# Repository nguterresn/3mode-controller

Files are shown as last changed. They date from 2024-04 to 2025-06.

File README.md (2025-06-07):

## **Hardware Controller for Hobbyist Projects with ESPNow, nRF24, and Bluetooth**

This versatile hardware controller is designed to seamlessly integrate with a variety of wireless communication protocols, making it an ideal choice for hobbyist projects, DIY electronics, and prototyping. With support for **ESPNow**, **nRF24**, and **Bluetooth**, this controller offers unparalleled flexibility for creating custom communication setups across different platforms.

IMG_9709 – grande

### **Key Features:**

- **ESPNow**: Leverage ESP32's ESPNow protocol for fast, low-power, peer-to-peer communication between ESP32 devices. Perfect for IoT projects where devices need to communicate without relying on Wi-Fi or internet connections.
  
- **nRF24**: Incorporates the nRF24 wireless transceiver, enabling reliable and efficient communication for projects using the popular nRF24L01 radio module. Ideal for low-power, long-range wireless setups.

- **Bluetooth**: Equipped with Bluetooth support, allowing wireless connectivity with smartphones, tablets, and other Bluetooth-enabled devices. This makes it perfect for projects that require mobile app interaction or Bluetooth-based control.

- **Versatile Connectivity**: Easily switch between the three wireless protocols based on the requirements of your project, enabling communication over short or long distances, with low or high power consumption.

- **Easy-to-Use Interface**: Simple to interface with microcontrollers like ESP32 or Arduino, with available libraries and example code to get you started quickly.

- **Low Power Consumption**: Designed with power efficiency in mind, making it suitable for battery-powered projects, especially when using ESPNow or nRF24 protocols.

With its easy integration, low power consumption, and flexible wireless communication options, this hardware controller is an essential tool for hobbyists and makers looking to bring their wireless project ideas to life.

### Support

- ✅ ESPNow
- ✅ nRF24
- ❌ Bluetooth (Work in progress)

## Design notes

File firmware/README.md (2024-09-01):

### Notes

Based on [ESP-IDF v5.1.4](https://docs.espressif.com/projects/esp-idf/en/v5.1.4/esp32/api-reference/index.html)

- Before anything do `get_idf`
- Build with `idf.py build`
- Check for serial devices with `ls /dev/tty.*`
- Flash with `idf.py -p DEVICE flash`

### CMake Notes

> In CMake terms, REQUIRES & PRIV_REQUIRES are approximate wrappers around the CMake functions target_link_libraries(... PUBLIC ...) and target_link_libraries(... PRIVATE ...).

### Arduino

- Installing [Arduino as a component](https://docs.espressif.com/projects/arduino-esp32/en/latest/esp-idf_component.html).

### Concepts about nRF24L01+

Channels control the frequency, pipes are a software term to channel.

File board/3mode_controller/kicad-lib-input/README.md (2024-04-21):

# kicad-lib-input

KiCAD Library for input parts.

- 2-axis Joystick #27800
- 2-axis Joystick RKJXV1224005

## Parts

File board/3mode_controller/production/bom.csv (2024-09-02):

Designator | Footprint | Quantity | Value | LCSC Part #
C1, C6, C9 | 0603 | 3 | 1u | C1592
C2, C4 | 0603 | 2 | 0.1u | C30926
C3, C5 | 0603 | 2 | 10u | C380316
D1 | 0603 | 1 | LED | C965799
D2 | 0603 | 1 | RLED
D3 | 0603 | 1 | GLED
D4 | D_SMB | 1 | VS-10BQ015HM3/5BT | C413465
H1, H2 | MountingHole_3.2mm_M3_ISO14580_Pad | 2 | MountingHole
IC1 | SOT-23-6_Handsoldering | 1 | DW01A | C351410
J1 | JST_PH_S2B-PH-K_1x02_P2.00mm_Horizontal | 1 | JST XH | C722769
J2 | USB_C_Receptacle_GCT_USB4105-xx-A_16P_TopMnt_Horizontal | 1 | USB_C_Receptacle | C2765186
Q1 | SOT-23 | 1 | FDN336P | C19188376
R1, R10, R3, R4, R6, R7 | 0603 | 6 | 5.1K | C2907114
R2 | 0603 | 1 | 1.2k | C118396
R5 | 0805 | 1 | 100 | C17408
R9 | 0603 | 1 | 1k | C328340
SW1 | SW_SPST_CK_RS282G05A3 | 1 | reset
SW2 | SW_SPST_CK_RS282G05A3 | 1 | boot
SW3 | SW_DIP_SPSTx04_Slide_9.78x12.34mm_W7.62mm_P2.54mm | 1 | SW_DIP_x04 | C25503179
SW4 | SW_Slide_1P2T_CK_OS102011MS2Q | 1 | SW_SPDT | C431548
U1 | SOP-8_3.9x4.9mm_P1.27mm | 1 | TP4056 | C16581
U2 | ESP32-S3-WROOM-1 | 1 | ESP32-S3-WROOM-1 | C2913198
U3 | SOT-23-5 | 1 | AP2112K-3.3 | C51118
U4 | SOT-23-6_Handsoldering | 1 | FH8205 | C2928988
U6 | nRF24L01_Breakout | 1 | NRF24L01_Breakout
U7, U8 | RKJXV1224005 | 2 | RKJXV1224005 | C918854

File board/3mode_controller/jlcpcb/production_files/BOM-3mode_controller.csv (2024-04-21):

Comment | Designator | Footprint | LCSC
1.2k | R2 | R_0603_1608Metric_Pad0.98x0.95mm_HandSolder | C118396
RKJXV1224005 | U7,U8 | RKJXV1224005 | C146170
1u | C1 | C_0603_1608Metric_Pad1.08x0.95mm_HandSolder | C1592
TP4056 | U1 | SOP-8_3.9x4.9mm_P1.27mm | C16581
100 | R5 | R_0805_2012Metric_Pad1.20x1.40mm_HandSolder | C17408
10u | C7,C8 | CP_EIA-3216-18_Kemet-A_Pad1.58x1.35mm_HandSolder | C185774
FDN336P | Q1 | SOT-23 | C19188376
SS14 | D4 | D_SMA | C2480
USB_C_Receptacle | J2 | USB_C_Receptacle_GCT_USB4105-xx-A_16P_TopMnt_Horizontal | C2765186
5.1K | R1,R10,R3,R4,R6,R7 | R_0603_1608Metric_Pad0.98x0.95mm_HandSolder | C2907114
ESP32-S3-WROOM-1 | U2 | ESP32-S3-WROOM-1 | C2913198
FH8205 | U4 | SOT-23-6_Handsoldering | C2928988
AMS1117-3.3 | U5 | SOT-223-3_TabPin2 | C2992570
0.1u | C2,C4 | C_0603_1608Metric_Pad1.08x0.95mm_HandSolder | C30926
1k | R9 | R_0603_1608Metric_Pad0.98x0.95mm_HandSolder | C328340
DW01A | IC1 | SOT-23-6_Handsoldering | C351410
10u | C3,C5,C6 | C_0603_1608Metric_Pad1.08x0.95mm_HandSolder | C380316
SW_SPDT | SW4 | SW_Slide_1P2T_CK_OS102011MS2Q | C431548
LED | D1 | LED_0603_1608Metric_Pad1.05x0.95mm_HandSolder | C965799
reset | SW1 | SW_SPST_CK_RS282G05A3
MountingHole | H3 | MountingHole_3.2mm_M3_ISO14580_Pad
GLED | D3 | LED_0603_1608Metric_Pad1.05x0.95mm_HandSolder
ChangeScreen | SW3 | SW_PUSH_6mm
MountingHole | H2 | MountingHole_3.2mm_M3_ISO14580_Pad
boot | SW2 | SW_SPST_CK_RS282G05A3
MountingHole | H1 | MountingHole_3.2mm_M3_ISO14580_Pad
MountingHole | H4 | MountingHole_3.2mm_M3_ISO14580_Pad
RLED | D2 | LED_0603_1608Metric_Pad1.05x0.95mm_HandSolder
Conn_01x04_Socket | J1 | PinHeader_1x04_P2.54mm_Vertical
NRF24L01_Breakout | U6 | nRF24L01_Breakout
18350-HOLDER | U3 | 18350-Holder

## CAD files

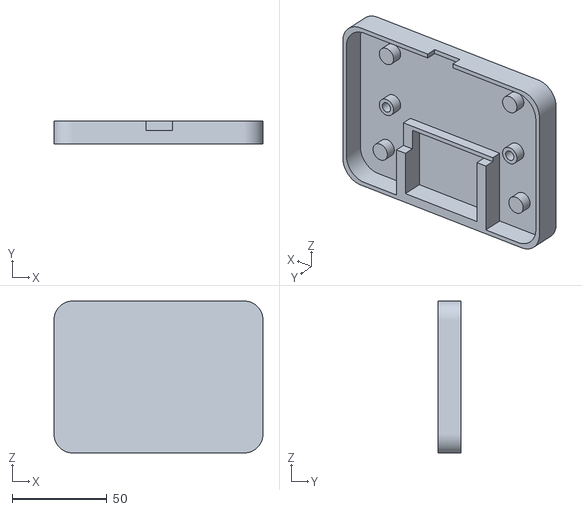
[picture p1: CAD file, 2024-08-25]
board/3mode_controller/DemoBody.stl
110.0 x 12.0 x 80.0

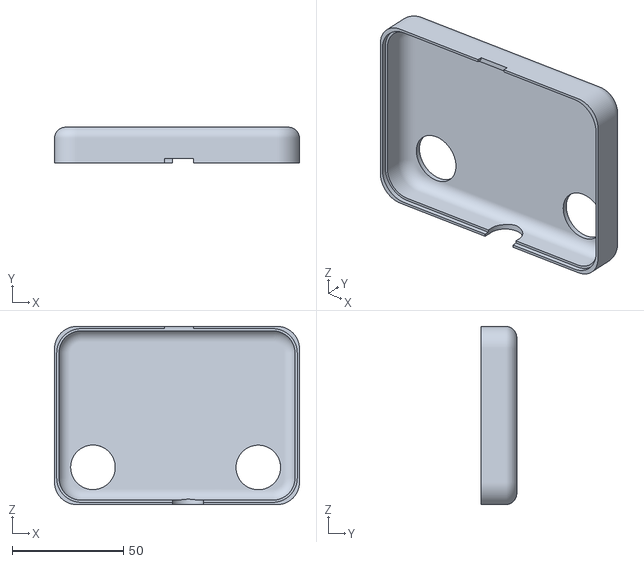
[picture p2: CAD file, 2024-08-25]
board/3mode_controller/Lid.stl
110.0 x 16.0 x 80.0

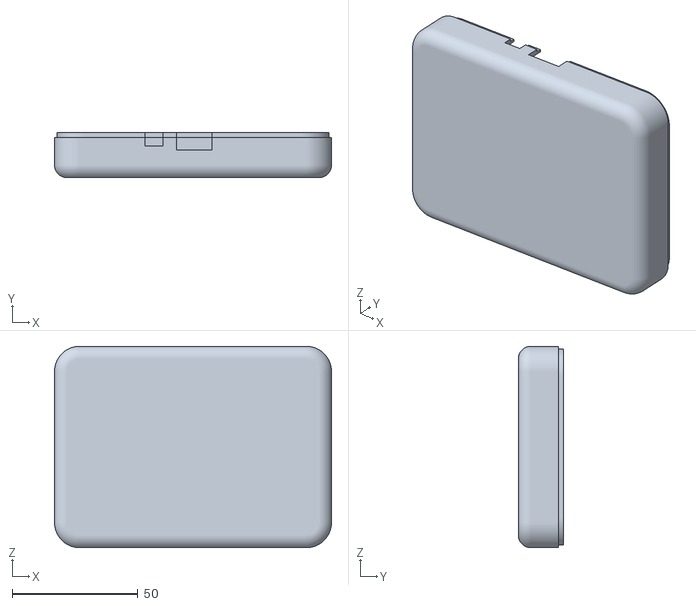
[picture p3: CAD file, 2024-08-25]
board/3mode_controller/Bottom.stl
110.0 x 18.0 x 80.0

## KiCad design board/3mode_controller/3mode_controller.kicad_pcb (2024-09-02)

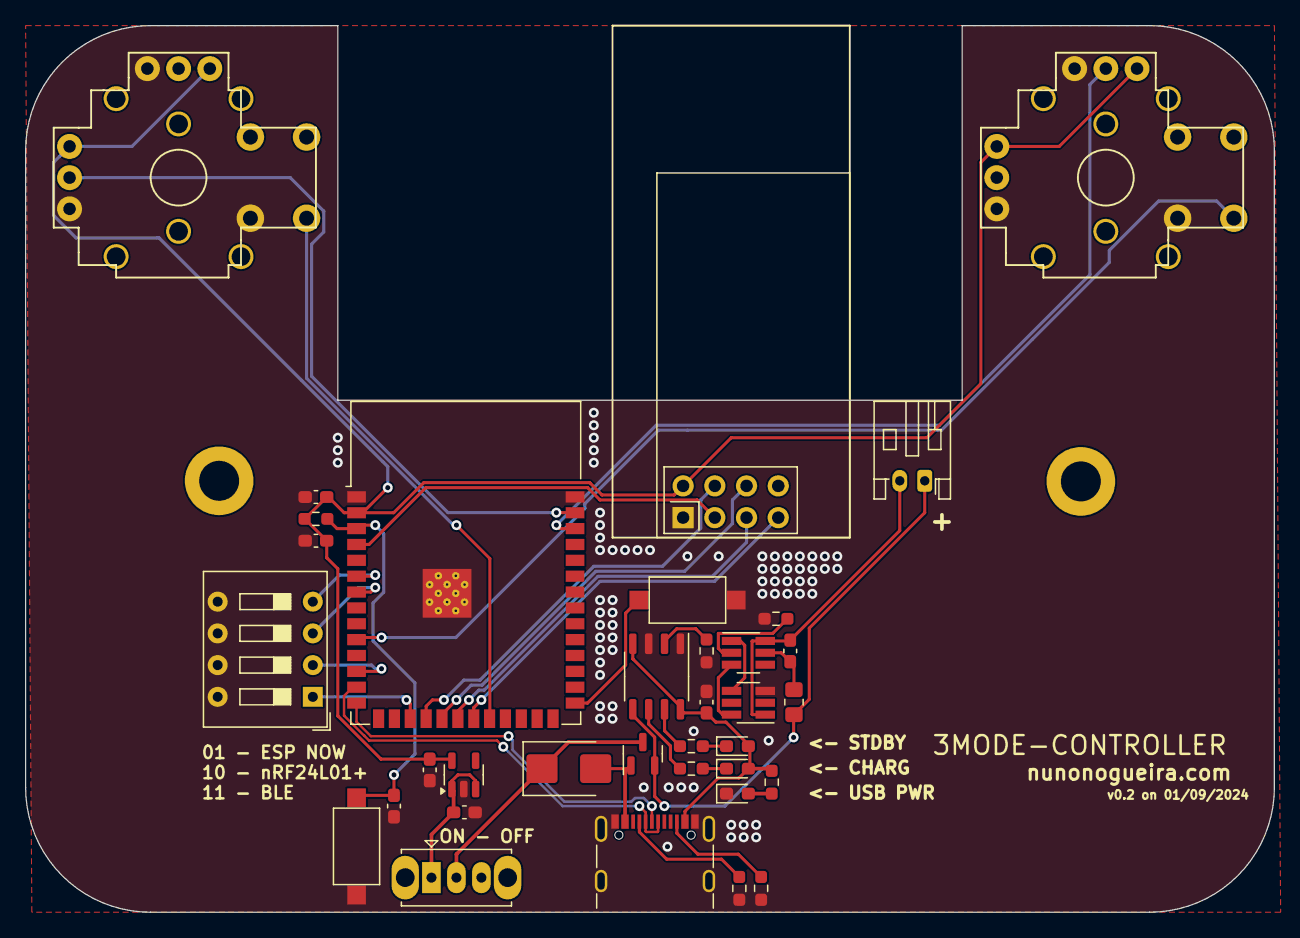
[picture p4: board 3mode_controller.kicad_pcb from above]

Board: 2 copper layers, 100.0 x 71.0 mm, 37 parts (0 on the bottom side), 36 nets.

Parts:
C1, C6, C9: 1u; C_0603_1608Metric_Pad1.08x0.95mm_HandSolder
C2, C4: 0.1u; C_0603_1608Metric_Pad1.08x0.95mm_HandSolder
C3, C5: 10u; C_0603_1608Metric_Pad1.08x0.95mm_HandSolder
D1: LED; LED_0603_1608Metric_Pad1.05x0.95mm_HandSolder
D2: RLED; LED_0603_1608Metric_Pad1.05x0.95mm_HandSolder
D3: GLED; LED_0603_1608Metric_Pad1.05x0.95mm_HandSolder
D4: VS-10BQ015HM3/5BT; D_SMB
H1, H2: MountingHole; MountingHole_3.2mm_M3_ISO14580_Pad
IC1: DW01A; SOT-23-6_Handsoldering
J1: JST XH; JST_PH_S2B-PH-K_1x02_P2.00mm_Horizontal
J2: USB_C_Receptacle; USB_C_Receptacle_GCT_USB4105-xx-A_16P_TopMnt_Horizontal
Q1: FDN336P; SOT-23
R1, R3, R4, R6, R7, R10: 5.1K; R_0603_1608Metric_Pad0.98x0.95mm_HandSolder
R2: 1.2k; R_0603_1608Metric_Pad0.98x0.95mm_HandSolder
R5: 100; R_0805_2012Metric_Pad1.20x1.40mm_HandSolder
R9: 1k; R_0603_1608Metric_Pad0.98x0.95mm_HandSolder
SW1: reset; SW_SPST_CK_RS282G05A3
SW2: boot; SW_SPST_CK_RS282G05A3
SW3: SW_DIP_x04; SW_DIP_SPSTx04_Slide_9.78x12.34mm_W7.62mm_P2.54mm
SW4: SW_SPDT; SW_Slide_1P2T_CK_OS102011MS2Q
U1: TP4056; SOP-8_3.9x4.9mm_P1.27mm
U2: ESP32-S3-WROOM-1
U3: AP2112K-3.3; SOT-23-5
U4: FH8205; SOT-23-6_Handsoldering
U6: NRF24L01_Breakout; nRF24L01_Breakout
U7, U8: RKJXV1224005

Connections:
+3.3V: C3.1, C5.1, C9.1, R1.1, U2.2 (3V3), U3.5 (VOUT), U6.2 (VCC), U7.1 (LR1), U7.4 (UD1), U8.1 (LR1), U8.4 (UD1)
+5V: C2.1, D2.2 (A), D3.2 (A), D4.2 (A), J2.A4 (VBUS), J2.A9 (VBUS), J2.B4 (VBUS), J2.B9 (VBUS), Q1.1 (G), R7.2, U1.4 (VCC), U1.8 (CE)
ESP32-BOOT0: SW2.1, U2.27 (GPIO0/BOOT)
ESP32-D+: J2.A6 (D+), J2.B6 (D+), U2.14 (GPIO20/U1CTS/ADC2_CH9/CLK_OUT1/USB_D+)
ESP32-D-: J2.A7 (D-), J2.B7 (D-), U2.13 (GPIO19/U1RTS/ADC2_CH8/CLK_OUT2/USB_D-)
ESP32-PULLUP-1: SW3.4, U2.6 (GPIO6/TOUCH6/ADC1_CH5)
ESP32-PULLUP-2: SW3.3, U2.7 (GPIO7/TOUCH7/ADC1_CH6)
ESP32-PULLUP-3: SW3.2, U2.12 (GPIO8/TOUCH8/ADC1_CH7/SUBSPICS1)
ESP32-PULLUP-4: SW3.1, U2.17 (GPIO9/TOUCH9/ADC1_CH8/FSPIHD/SUBSPIHD)
ESP32-RESET: C1.1, R1.2, SW1.1, U2.3 (EN)
ESP32_JOYSTICK_X: U2.38 (GPIO2/TOUCH2/ADC1_CH1), U8.2 (LR2)
ESP32_JOYSTICK_Y: U2.39 (GPIO1/TOUCH1/ADC1_CH0), U7.5 (UD2)
ESP32_RF_SPI_CE: U2.4 (GPIO4/TOUCH4/ADC1_CH3), U6.3 (CE)
ESP32_RF_SPI_CNS: U2.18 (GPIO10/TOUCH10/ADC1_CH9/FSPICS0/FSPIIO4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), U6.4 (~CSN)
ESP32_RF_SPI_MISO: U2.21 (GPIO13/TOUCH13/ADC2_CH2/FSPIQ/FSPIIO7/S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), U6.7 (MISO)
ESP32_RF_SPI_MOSI: U2.19 (GPIO11/TOUCH11/ADC2_CH0/FSPID/FSPIIO5/S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), U6.6 (MOSI)
ESP32_RF_SPI_SCK: U2.20 (GPIO12/TOUCH12/ADC2_CH1/FSPICLK/FSPIIO6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), U6.5 (SCK)
GND: C1.2, C2.2, C3.2, C5.2, C6.2, C9.2, D1.1 (K), J2.A1 (GND), J2.A12 (GND), J2.B1 (GND), J2.B12 (GND), J2.S1 (SHIELD), R2.2, R3.1, R4.2, R9.1, SW1.2, SW2.2, SW3.5, SW3.6, SW3.7, SW3.8, U1.1 (TEMP), U1.3 (GND), U2.1 (GND), U2.40 (GND), U2.41 (GND), U3.2 (GND), U4.3 (S2), U6.1 (GND), U7.3 (LR3), U7.6 (UD3), U7.7 (SWa), U8.3 (LR3), U8.6 (UD3), U8.7 (SWa)
JS_LEFT_IRQ: U2.22 (GPIO14/TOUCH14/ADC2_CH3/FSPIWP/FSPIDQS/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), U7.8 (SWb)
JS_RIGHT_IRQ: U2.10 (GPIO17/U1TXD/ADC2_CH6), U8.8 (SWb)
unnamed: D1.2 (A), R7.1
unnamed: D2.1 (K), R10.1
unnamed: D3.1 (K), R6.1
unnamed: IC1.2 (CS), R9.2
unnamed: C4.2, IC1.6 (GND), J1.2, U4.1 (S1)
unnamed: IC1.3 (OC), U4.6 (G2)
unnamed: IC1.1 (OD), U4.4 (G1)
unnamed: C4.1, IC1.5 (VCC), R5.2
unnamed: J2.A5 (CC1), R3.2
unnamed: J2.B5 (CC2), R4.1
unnamed: C6.1, SW4.1 (A), U3.1 (VIN), U3.3 (EN)
unnamed: R2.1, U1.2 (PROG)
unnamed: R10.2, U1.7 (~CHRG)
unnamed: R6.2, U1.6 (~STDBY)
VBAT+PROTECT: J1.1, Q1.2 (S), R5.1, U1.5 (BAT)
VSPLY: D4.1 (K), Q1.3 (D), SW4.2 (B)

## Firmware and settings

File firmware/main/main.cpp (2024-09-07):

#include "Arduino.h"
#include "HardwareSerial.h"
#include "app.h"
#include "dip.h"
#include "espnow.h"
#include "gpio_list.h"
#include "joystick.h"
#include "modes.h"
#include "nrf24.h"

static struct joystick js_x;
static struct joystick js_y;
static struct app      app_esp_now;
static struct app      app_nrf;

static void check_and_change_app(void);

void setup()
{
  Serial.begin(115200);
  while (!Serial) {
    ; // wait for serial port to connect
  }

  dip_init();
  joystick_init(&js_x, GPIO_JOYSTICK_X, GPIO_JOYSTICK_X_IRQ);
  joystick_init(&js_y, GPIO_JOYSTICK_Y, GPIO_JOYSTICK_Y_IRQ);

  app_install(&app_esp_now, espnow_init, espnow_deinit, espnow_send, NULL);
  app_install(&app_nrf, nrf24_init, nrf24_deinit, nrf24_send, NULL);

  check_and_change_app();
}

void loop()
{
  // (1) Check DIP.
  if (dip_has_changed()) {
    check_and_change_app();
  }

  // (2) Check Joysticks.
  if (joystick_has_moved(&js_x) != -1 || joystick_has_moved(&js_y) != -1) {
    struct js_stamp stamp = {
      .x = js_x.read,
      .y = js_y.read,
    };
    app_send(&stamp);
  }
}

static void check_and_change_app(void)
{
  uint8_t read = dip_read();

  Serial.printf("Value for the DIP4 '%02x'\n", (int)read);
  switch (read) {
  case DIP_ESP_NOW:
    app_next(&app_esp_now);
    break;
  case DIP_NRF:
    app_next(&app_nrf);
    break;
  default:
    // Other: nothing.
    app_next(NULL);
    break;
  }
}

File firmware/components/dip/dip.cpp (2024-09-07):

#include "dip.h"
#include "Arduino.h"
#include "esp32-hal-gpio.h"
#include "gpio_list.h"
#include <stdint.h>

static SemaphoreHandle_t sem;
static void              dip_changed(void);

void dip_init()
{
  pinMode(GPIO_DIP_1, INPUT_PULLUP);
  pinMode(GPIO_DIP_2, INPUT_PULLUP);
  pinMode(GPIO_DIP_3, INPUT_PULLUP);
  pinMode(GPIO_DIP_4, INPUT_PULLUP);

  attachInterrupt(digitalPinToInterrupt(GPIO_DIP_1), dip_changed, CHANGE);
  attachInterrupt(digitalPinToInterrupt(GPIO_DIP_2), dip_changed, CHANGE);
  attachInterrupt(digitalPinToInterrupt(GPIO_DIP_3), dip_changed, CHANGE);
  attachInterrupt(digitalPinToInterrupt(GPIO_DIP_4), dip_changed, CHANGE);

  sem = xSemaphoreCreateBinary();
  if (!sem) {
    exit(-1);
  }
}

uint8_t dip_read(void)
{
  // Note: GPIO_DIP_1 holds the LSB.
  return (digitalRead(GPIO_DIP_4) & 0x01) |
         ((digitalRead(GPIO_DIP_3) & 0x01) << 1) |
         ((digitalRead(GPIO_DIP_2) & 0x01) << 2) |
         ((digitalRead(GPIO_DIP_1) & 0x01) << 3);
}

static void dip_changed(void)
{
  xSemaphoreGiveFromISR(sem, NULL);
}

bool dip_has_changed(void)
{
  return xSemaphoreTake(sem, 0) ? true : false;
}

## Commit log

2024-04-21 started working on the schematic
    [3mode_controller.kicad_pcb, 3mode_controller.kicad_sch]
2024-04-21 schematic finished
    [3mode_controller.kicad_sch]
2024-04-21 New pins for esp32s3
2024-04-21 added the joysticks to the schematic
    [3mode_controller.kicad_sch]
2024-04-21 added symbols and footprints for the battery charging ICs
    [3mode_controller.kicad_sch]
2024-04-21 first pcb version
    [3mode_controller-CuBottom.gbr, 3mode_controller-CuTop.gbr, 3mode_controller-EdgeCuts.gbr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]
2024-04-21 updated one missing footprint
    [3mode_controller-CuBottom.gbr, 3mode_controller-CuTop.gbr, 3mode_controller-EdgeCuts.gbr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]
2024-08-04 first prototype board
    [3mode_controller.kicad_pcb, 3mode_controller.kicad_sch, bom.csv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]
2024-08-25 a lot of changes but still a work in progress !
    [Bottom.stl, DemoBody.stl, Lid.stl]
2024-09-02 v0.2.
    Replaced diode and LDO
    [3mode_controller.kicad_pcb, 3mode_controller.kicad_sch, bom.csv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]
